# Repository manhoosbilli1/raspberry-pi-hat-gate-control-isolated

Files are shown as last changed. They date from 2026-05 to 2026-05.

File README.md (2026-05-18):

# GATE CONTROL HAT v1.2

Raspberry Pi HAT for gate control with PC817 optocoupler-isolated power / lock monitoring inputs (v1.2)

## At a Glance

- **Status**: In progress
- **Board size**: 65 x 56 mm
- **Layers**: 2
- **Components**: 5
- **Key ICs**:
  - U1,U2: PC817

## Schematic

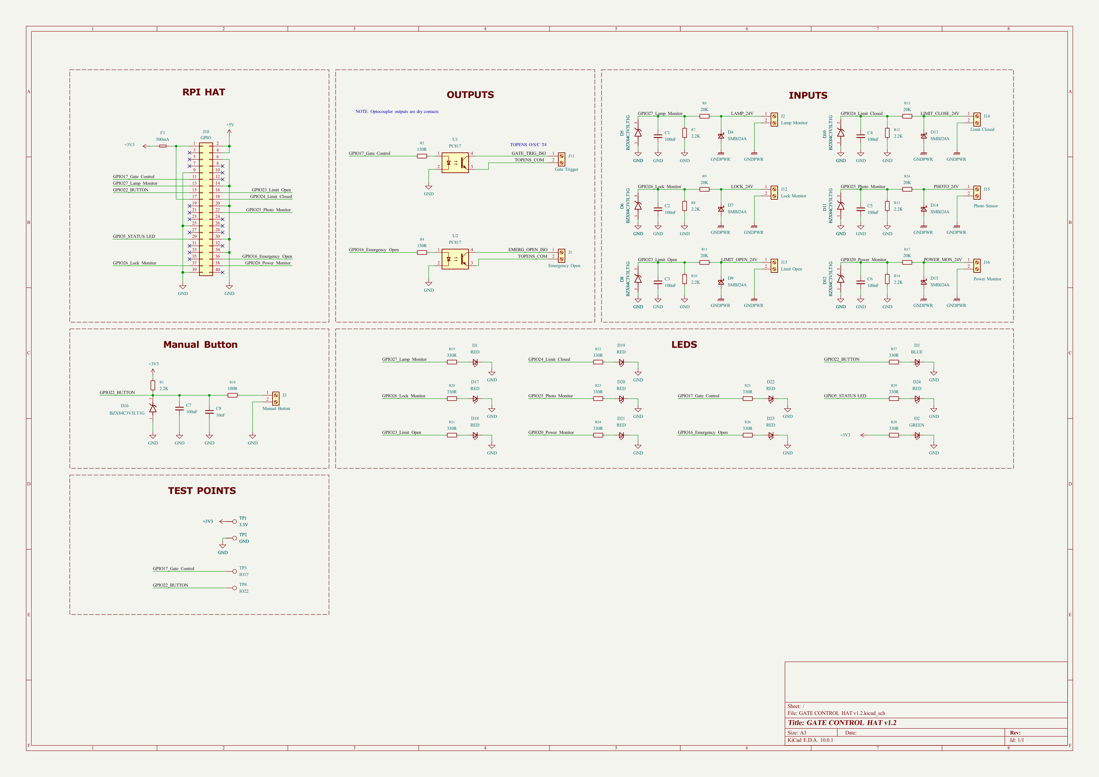
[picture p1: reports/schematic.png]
Schematic


Full PDF: [reports/schematic.pdf](reports/schematic.pdf)

## Component Roles

- **40-pin RPi GPIO header** (Conn_02x20) - stacks onto a Raspberry Pi as a HAT
- **PC817** optocouplers (multiple) - galvanic isolation for the field-side inputs (Power Monitor + Lock Monitor); protects the Pi from voltage spikes on long field cables
- **SMBJ24A** - 24 V TVS diode for surge protection on the field input lines
- **BZX84C3V3LT1G** - 3.3 V zener for input clamp/reference
- **Screw terminals** for field wiring (gate sensors, lock contacts)
- **500 mA fuse** for input protection
- Status LEDs (Green) to indicate input state at a glance during commissioning

## PCB

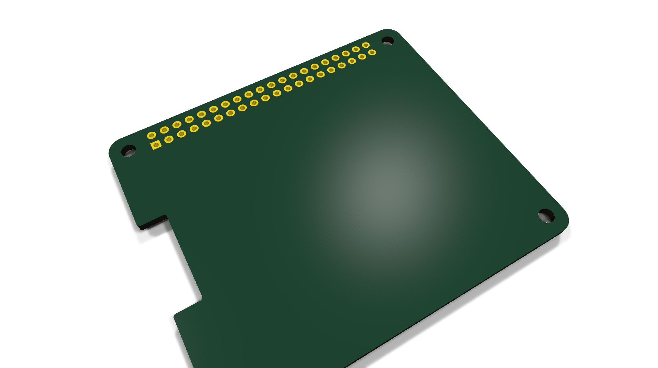
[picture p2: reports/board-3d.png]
3D top


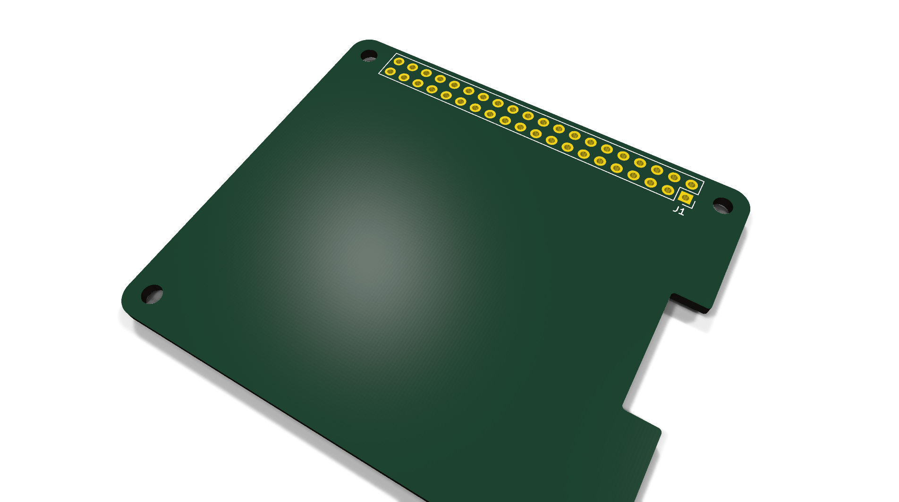
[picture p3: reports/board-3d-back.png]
3D bottom


**Top copper**

PCB top

**Bottom copper**

PCB bottom

## Bill of Materials

| Refs | Value | Footprint | Qty | MPN | LCSC |
|---|---|---|----:|-----|---|
| C1-C7 | 100nF | Capacitor_SMD:C_0805_2012Metric | 7 |  |  |
| C8 | 10nF | Capacitor_SMD:C_0805_2012Metric | 1 |  |  |
| D1,D17-D24 | RED | LED_SMD:LED_0805_2012Metric | 9 |  |  |
| D2 | GREEN | LED_SMD:LED_0805_2012Metric | 1 |  |  |
| D3 | BLUE | LED_SMD:LED_0805_2012Metric | 1 |  |  |
| D4,D7,D9,D13-D15 | SMBJ24A | Diode_SMD:D_SMB | 6 |  |  |
| D5,D6,D8,D10-D12,D16 | BZX84C3V3LT1G | BZX84C3V3LT1G:SOT95P240X111-3N | 7 |  |  |
| F1 | 500mA | Fuse:Fuse_1206_3216Metric | 1 |  |  |
| J1 | Emergency Open | TerminalBlock_4Ucon:TerminalBlock_4Ucon_1x02_P3.50mm_Vertical | 1 |  |  |
| J2 | Lamp Monitor | TerminalBlock_4Ucon:TerminalBlock_4Ucon_1x02_P3.50mm_Vertical | 1 |  |  |
| J3 | Manual Button | TerminalBlock_4Ucon:TerminalBlock_4Ucon_1x02_P3.50mm_Vertical | 1 |  |  |
| J10 | GPIO | Connector_PinSocket_2.54mm:PinSocket_2x20_P2.54mm_Vertical | 1 |  |  |
| J11 | Gate Trigger | TerminalBlock_4Ucon:TerminalBlock_4Ucon_1x02_P3.50mm_Vertical | 1 |  |  |
| J12 | Lock Monitor | TerminalBlock_4Ucon:TerminalBlock_4Ucon_1x02_P3.50mm_Vertical | 1 |  |  |
| J13 | Limit Open | TerminalBlock_4Ucon:TerminalBlock_4Ucon_1x02_P3.50mm_Vertical | 1 |  |  |
| J14 | Limit Closed | TerminalBlock_4Ucon:TerminalBlock_4Ucon_1x02_P3.50mm_Vertical | 1 |  |  |
| J15 | Photo Sensor | TerminalBlock_4Ucon:TerminalBlock_4Ucon_1x02_P3.50mm_Vertical | 1 |  |  |
| J16 | Power Monitor | TerminalBlock_4Ucon:TerminalBlock_4Ucon_1x02_P3.50mm_Vertical | 1 |  |  |
| R1,R7,R8,R10,R12-R14 | 2.2K | Resistor_SMD:R_0805_2012Metric | 7 |  |  |
| R2,R4 | 150R | Resistor_SMD:R_0805_2012Metric | 2 |  |  |
| R6,R9,R11,R15-R17 | 20K | Resistor_SMD:R_0805_2012Metric | 6 |  |  |
| R18 | 100R | Resistor_SMD:R_0805_2012Metric | 1 |  |  |
| R19-R29 | 330R | Resistor_SMD:R_0805_2012Metric | 11 |  |  |
| U1,U2 | PC817 | Package_DIP:DIP-4_W7.62mm_SMDSocket_SmallPads | 2 |  |  |

_24 of 24 line items don't have an LCSC code in the schematic - search [LCSC](https://www.lcsc.com/) or [JLC parts search](https://jlcsearch.tscircuit.com/) by MPN or footprint when sourcing._

## Files

- `GATE CONTROL HAT v1.2.kicad_pro` - KiCad project
- `GATE CONTROL HAT v1.2.kicad_sch` - schematic source
- `GATE CONTROL HAT v1.2.kicad_pcb` - PCB layout source
- `reports/schematic.pdf` - full schematic (printable)
- `reports/bom.csv` - bill of materials
- `reports/pcb-top.svg`, `reports/pcb-bottom.svg` - copper artwork
- `reports/board-stats.json` - KiCad-generated board statistics

---

_Renders and metadata auto-generated by `Backup-KiCadProject.ps1` using KiCad 10.0._

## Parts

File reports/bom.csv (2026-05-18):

Refs | Value | Footprint | Qty | Description | Mfr | MPN | LCSC
C1-C7 | 100nF | Capacitor_SMD:C_0805_2012Metric | 7 | 100V 100nF X7R ±10% 0805 Multilayer Ceramic Capacitors MLCC - SMD/SMT ROHS
C8 | 10nF | Capacitor_SMD:C_0805_2012Metric | 1 | 10nF 50V X7R ±10% 0805 Multilayer Ceramic Capacitors MLCC - SMD/SMT ROHS
D1,D17-D24 | RED | LED_SMD:LED_0805_2012Metric | 9 | -30℃~+85℃ 1.6V~2.6V 130° 195mcd 25mA 615nm~630nm 630nm 65mW Discrete Diode Red 0805 LED Indication - Discrete ROHS
D2 | GREEN | LED_SMD:LED_0805_2012Metric | 1 | -30℃~+85℃ 130° 2.5V~3.6V 20mA 400mcd 520nm 525nm~537.5nm 72mW Green 0805 LED Indication - Discrete ROHS
D3 | BLUE | LED_SMD:LED_0805_2012Metric | 1 | -30℃~+85℃ 130° 2.5V~3.6V 20mA 465nm 468nm~478nm 55mcd 72mW Blue 0805 LED Indication - Discrete ROHS
D4,D7,D9,D13-D15 | SMBJ24A | Diode_SMD:D_SMB | 6 | -65℃~+150℃ 15.5A@10/1000us 1uA 24V 29.5V 38.9V 390pF 600W@10/1000us IEC 61000-4-2 TVS Unidirectional DO-214AA(SMB) ESD and Surge Protection (TVS/ESD) ROHS
D5,D6,D8,D10-D12,D16 | BZX84C3V3LT1G | BZX84C3V3LT1G:SOT95P240X111-3N | 7 | -65℃~+150℃ 250mW 3.1V~3.5V 3.3V 5uA@1V 95Ω Independent SOT-23 Zener Diodes ROHS
F1 | 500mA | Fuse:Fuse_1206_3216Metric | 1 | -40℃~+85℃ 150mΩ 1A 24V 40A 500mA 600mW 700mΩ 8s 1206 Resettable Fuses ROHS
J1 | Emergency Open | TerminalBlock_4Ucon:TerminalBlock_4Ucon_1x02_P3.50mm_Vertical | 1 | Generic screw terminal, single row, 01x02, script generated (kicad-library-utils/schlib/autogen/connector/)
J2 | Lamp Monitor | TerminalBlock_4Ucon:TerminalBlock_4Ucon_1x02_P3.50mm_Vertical | 1 | Generic screw terminal, single row, 01x02, script generated (kicad-library-utils/schlib/autogen/connector/)
J3 | Manual Button | TerminalBlock_4Ucon:TerminalBlock_4Ucon_1x02_P3.50mm_Vertical | 1 | Generic screw terminal, single row, 01x02, script generated (kicad-library-utils/schlib/autogen/connector/)
J10 | GPIO | Connector_PinSocket_2.54mm:PinSocket_2x20_P2.54mm_Vertical | 1 | -40℃~+105℃ 2 2.54mm 2.54mm 2.5A 2x20P 40P 8.5mm Square Hole Through Hole Top Plugin,P=2.54mm Female Headers ROHS
J11 | Gate Trigger | TerminalBlock_4Ucon:TerminalBlock_4Ucon_1x02_P3.50mm_Vertical | 1 | Generic screw terminal, single row, 01x02, script generated (kicad-library-utils/schlib/autogen/connector/)
J12 | Lock Monitor | TerminalBlock_4Ucon:TerminalBlock_4Ucon_1x02_P3.50mm_Vertical | 1 | Generic screw terminal, single row, 01x02, script generated (kicad-library-utils/schlib/autogen/connector/)
J13 | Limit Open | TerminalBlock_4Ucon:TerminalBlock_4Ucon_1x02_P3.50mm_Vertical | 1 | Generic screw terminal, single row, 01x02, script generated (kicad-library-utils/schlib/autogen/connector/)
J14 | Limit Closed | TerminalBlock_4Ucon:TerminalBlock_4Ucon_1x02_P3.50mm_Vertical | 1 | Generic screw terminal, single row, 01x02, script generated (kicad-library-utils/schlib/autogen/connector/)
J15 | Photo Sensor | TerminalBlock_4Ucon:TerminalBlock_4Ucon_1x02_P3.50mm_Vertical | 1 | Generic screw terminal, single row, 01x02, script generated (kicad-library-utils/schlib/autogen/connector/)
J16 | Power Monitor | TerminalBlock_4Ucon:TerminalBlock_4Ucon_1x02_P3.50mm_Vertical | 1 | Generic screw terminal, single row, 01x02, script generated (kicad-library-utils/schlib/autogen/connector/)
R1,R7,R8,R10,R12-R14 | 2.2K | Resistor_SMD:R_0805_2012Metric | 7 | -55℃~+155℃ 125mW 150V 2.2kΩ Thick Film Resistor ±1% ±100ppm/℃ 0805 Chip Resistor - Surface Mount ROHS
R2,R4 | 150R | Resistor_SMD:R_0805_2012Metric | 2 | -55℃~+155℃ 125mW 150V 150Ω Thick Film Resistor ±1% ±100ppm/℃ 0805 Chip Resistor - Surface Mount ROHS
R6,R9,R11,R15-R17 | 20K | Resistor_SMD:R_0805_2012Metric | 6 | -55℃~+155℃ 125mW 150V 20kΩ Thick Film Resistor ±1% ±100ppm/℃ 0805 Chip Resistor - Surface Mount ROHS
R18 | 100R | Resistor_SMD:R_0805_2012Metric | 1 | -55℃~+155℃ 100Ω 125mW 150V Thick Film Resistor ±1% ±100ppm/℃ 0805 Chip Resistor - Surface Mount ROHS
R19-R29 | 330R | Resistor_SMD:R_0805_2012Metric | 11 | -55℃~+155℃ 125mW 150V 330Ω Thick Film Resistor ±1% ±100ppm/℃ 0805 Chip Resistor - Surface Mount ROHS
U1,U2 | PC817 | Package_DIP:DIP-4_W7.62mm_SMDSocket_SmallPads | 2 | DC Optocoupler, Vce 35V, CTR 50-300%, DIP-4

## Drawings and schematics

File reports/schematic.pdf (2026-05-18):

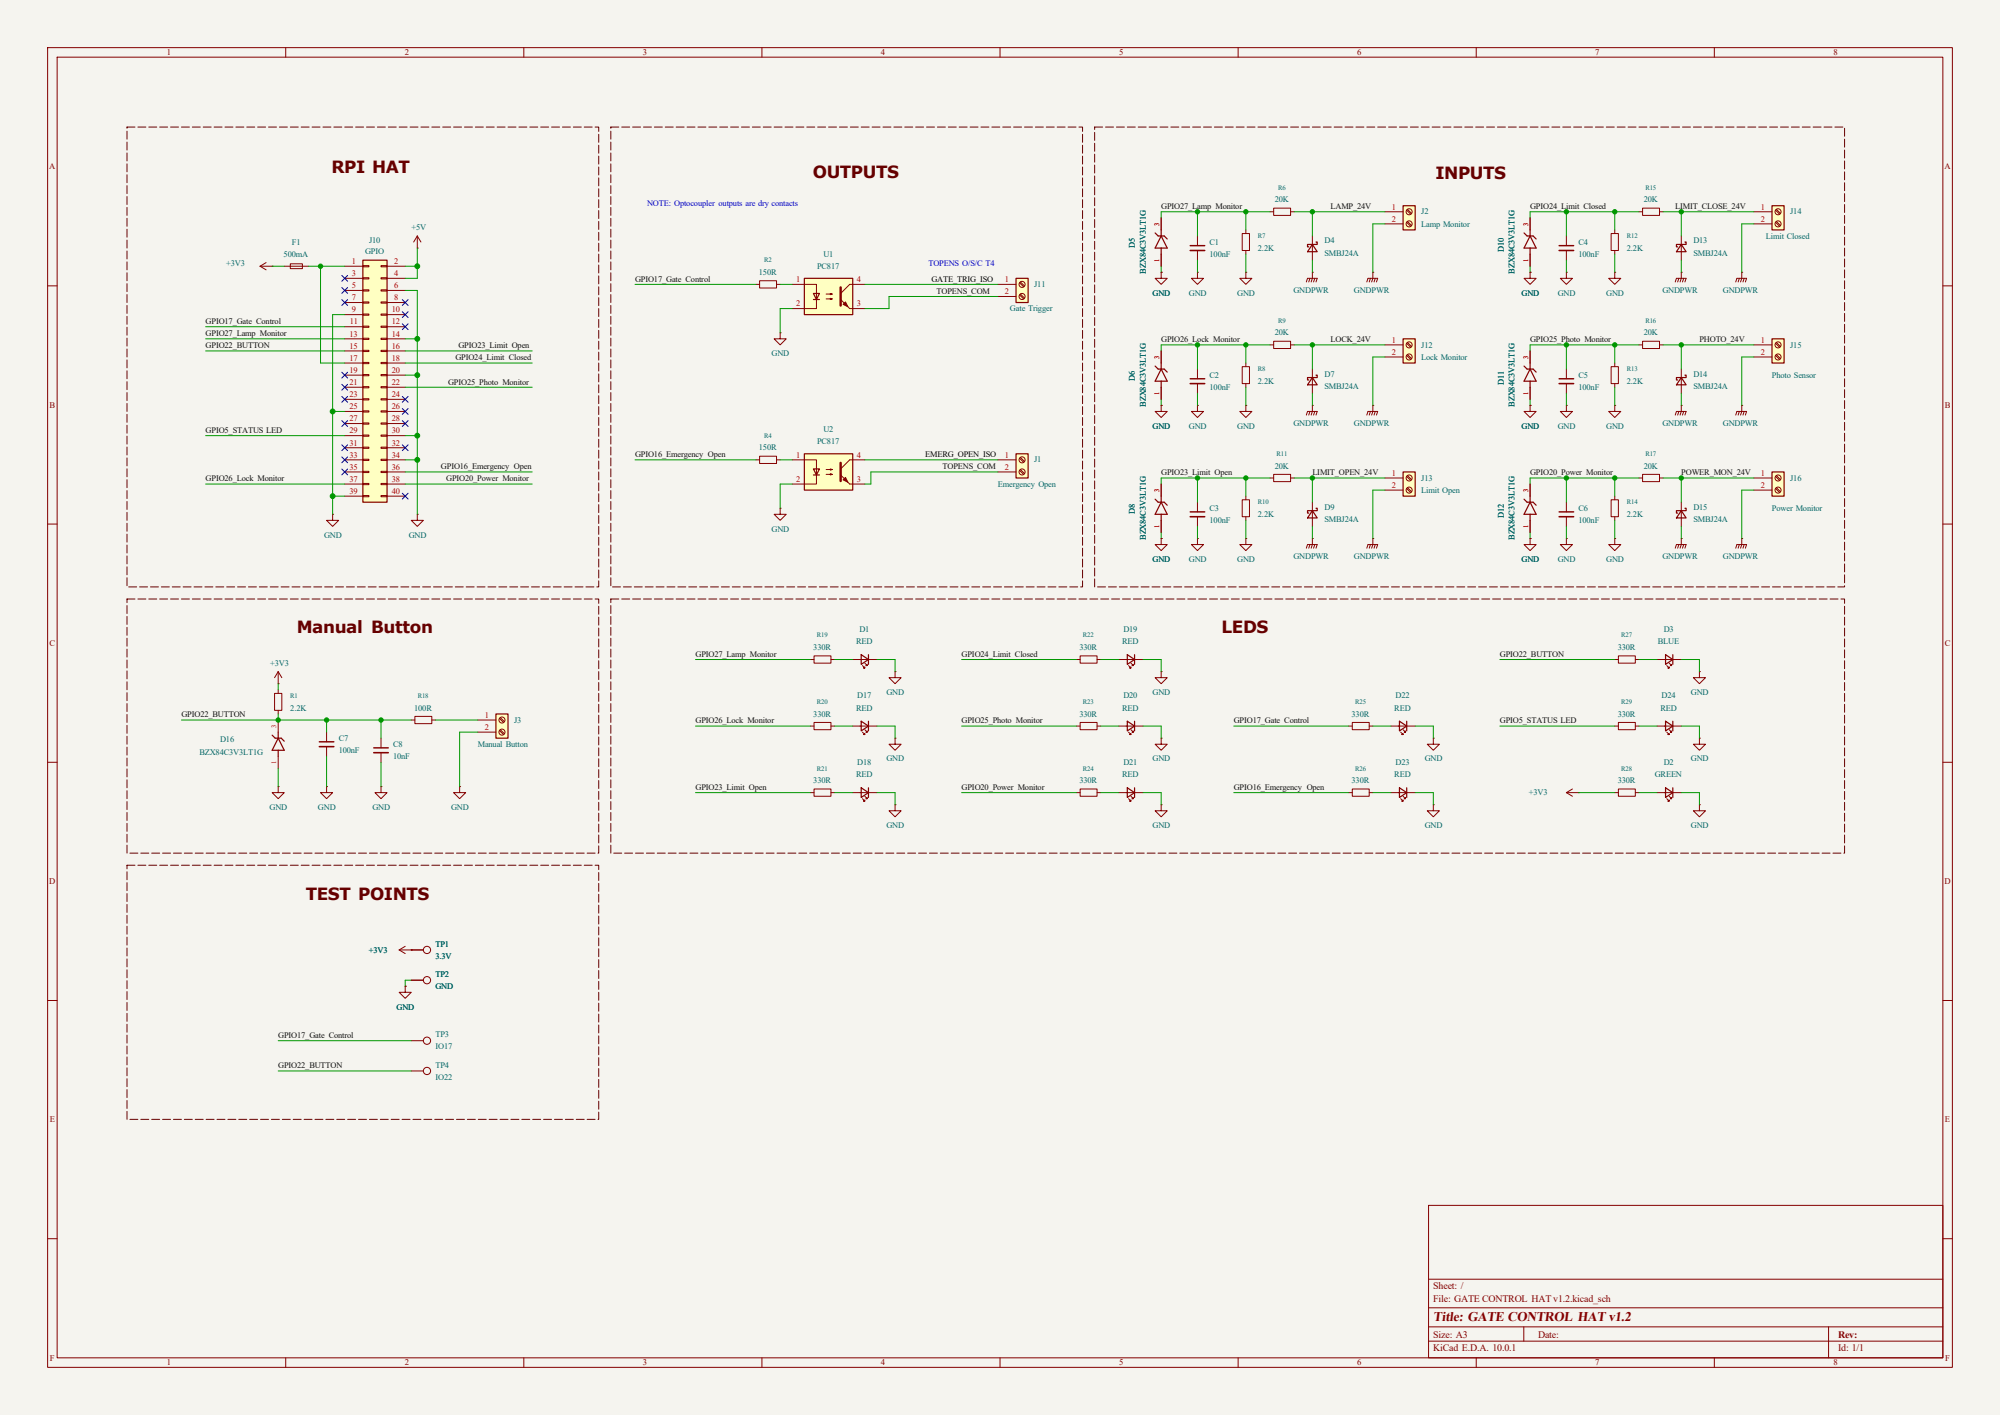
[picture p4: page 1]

GPIO25_Photo Monitor GPIO24_Limit Closed GPIO20_Power Monitor GPIO27_Lamp Monitor GPIO23_Limit Open

File: GATE CONTROL HAT v1.2.kicad_sch Sheet: /

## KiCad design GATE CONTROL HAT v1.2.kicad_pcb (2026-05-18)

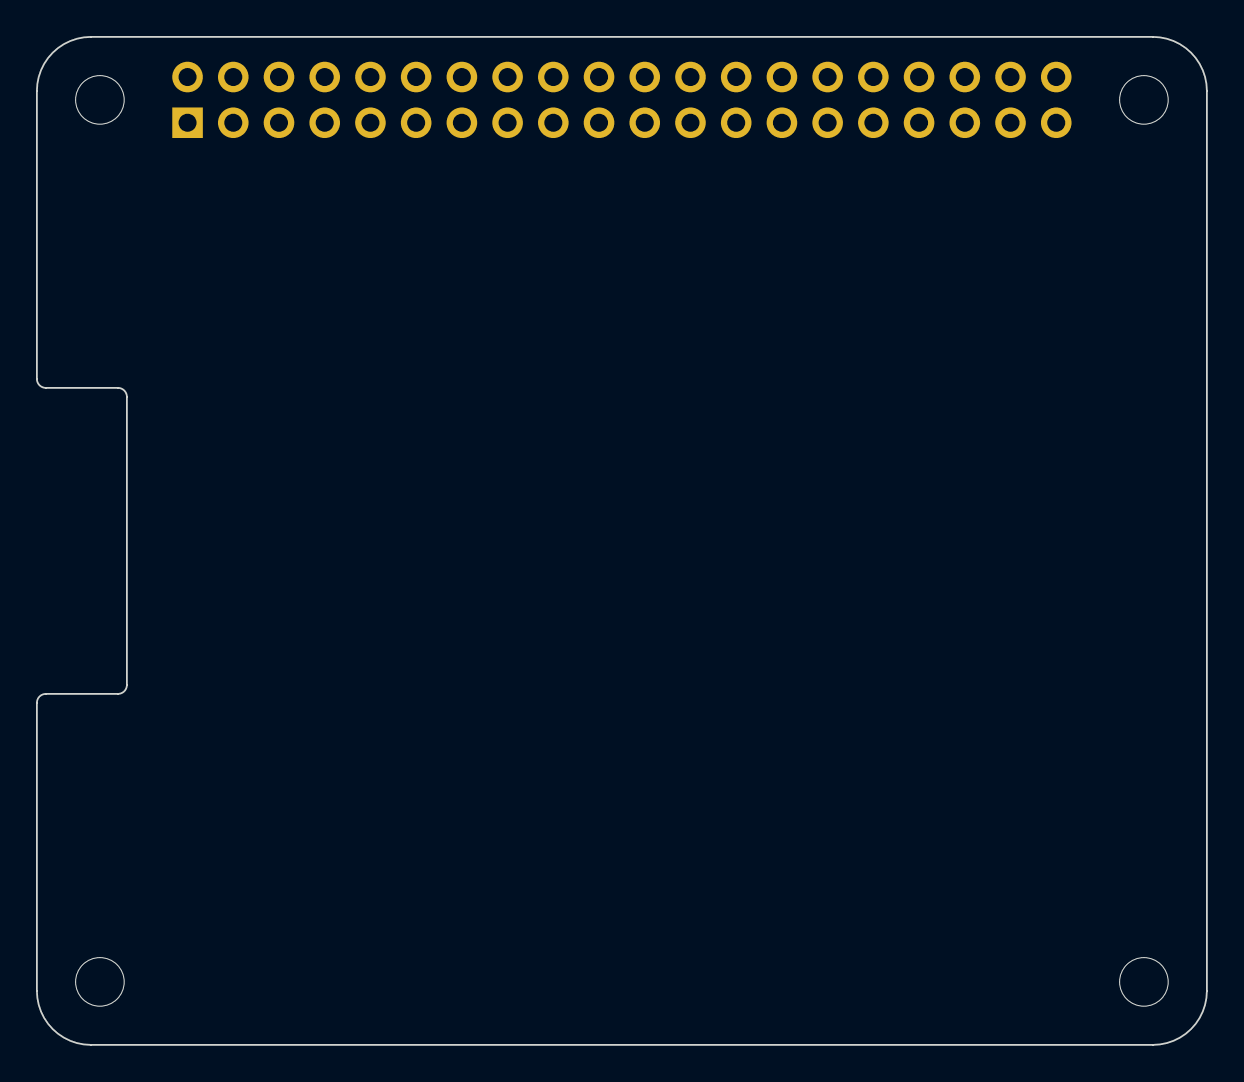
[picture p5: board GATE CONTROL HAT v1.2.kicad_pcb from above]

Board: 2 copper layers, 65.0 x 56.0 mm, 5 parts (1 on the bottom side), 3 nets, no tracks yet.

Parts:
J1: GPIO; PinSocket_2x20_P2.54mm_Vertical
MH1, MH2, MH3, MH4: MountingHole_2.7mm_M2.5

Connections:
+3V3: J1.1, J1.17
+5V: J1.2, J1.4
GND: J1.6, J1.9, J1.14, J1.20, J1.25, J1.30, J1.34, J1.39

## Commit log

2026-05-18 Update backup artifacts
    [GATE CONTROL HAT v1.2.kicad_pcb, GATE CONTROL HAT v1.2.kicad_sch, bom.csv]
2026-05-18 Enrich README: schematic PNG, component roles, BOM table
